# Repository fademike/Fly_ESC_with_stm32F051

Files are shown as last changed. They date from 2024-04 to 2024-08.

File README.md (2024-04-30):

# Fly_ESC_with_stm32F051
ESC for brushless motors.

git clone https://github.com/AlkaMotors/AM32-MultiRotor-ESC-firmware
git current project
cd AM32-MultiRotor-ESC-firmware
git apply am32ref_f051.patch (from current project)
May be to change make/tools: GCC_REQUIRED_VERSION ?= 10.3.1
make f051
STM32_Programmer_CLI -c port=swd -w ./obj/AM32_AM32REF_F051_2.00.bin 0x08000000 –verify -hardRst

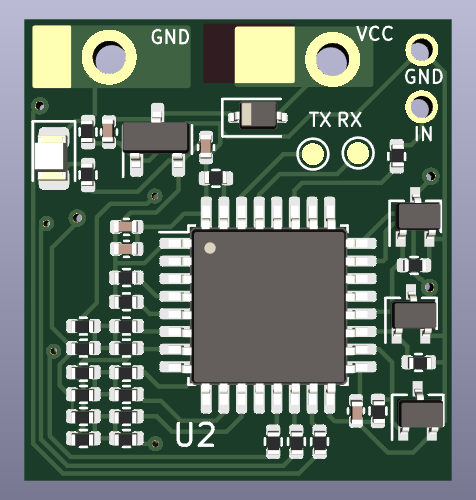
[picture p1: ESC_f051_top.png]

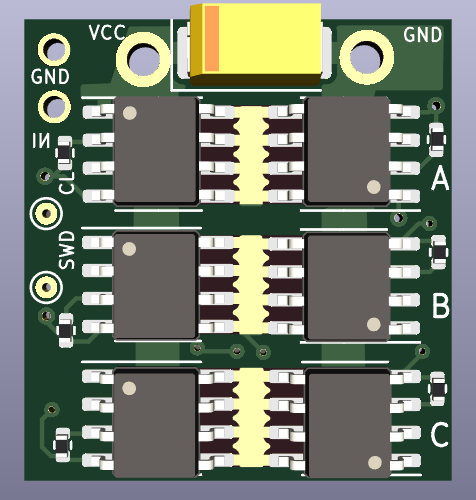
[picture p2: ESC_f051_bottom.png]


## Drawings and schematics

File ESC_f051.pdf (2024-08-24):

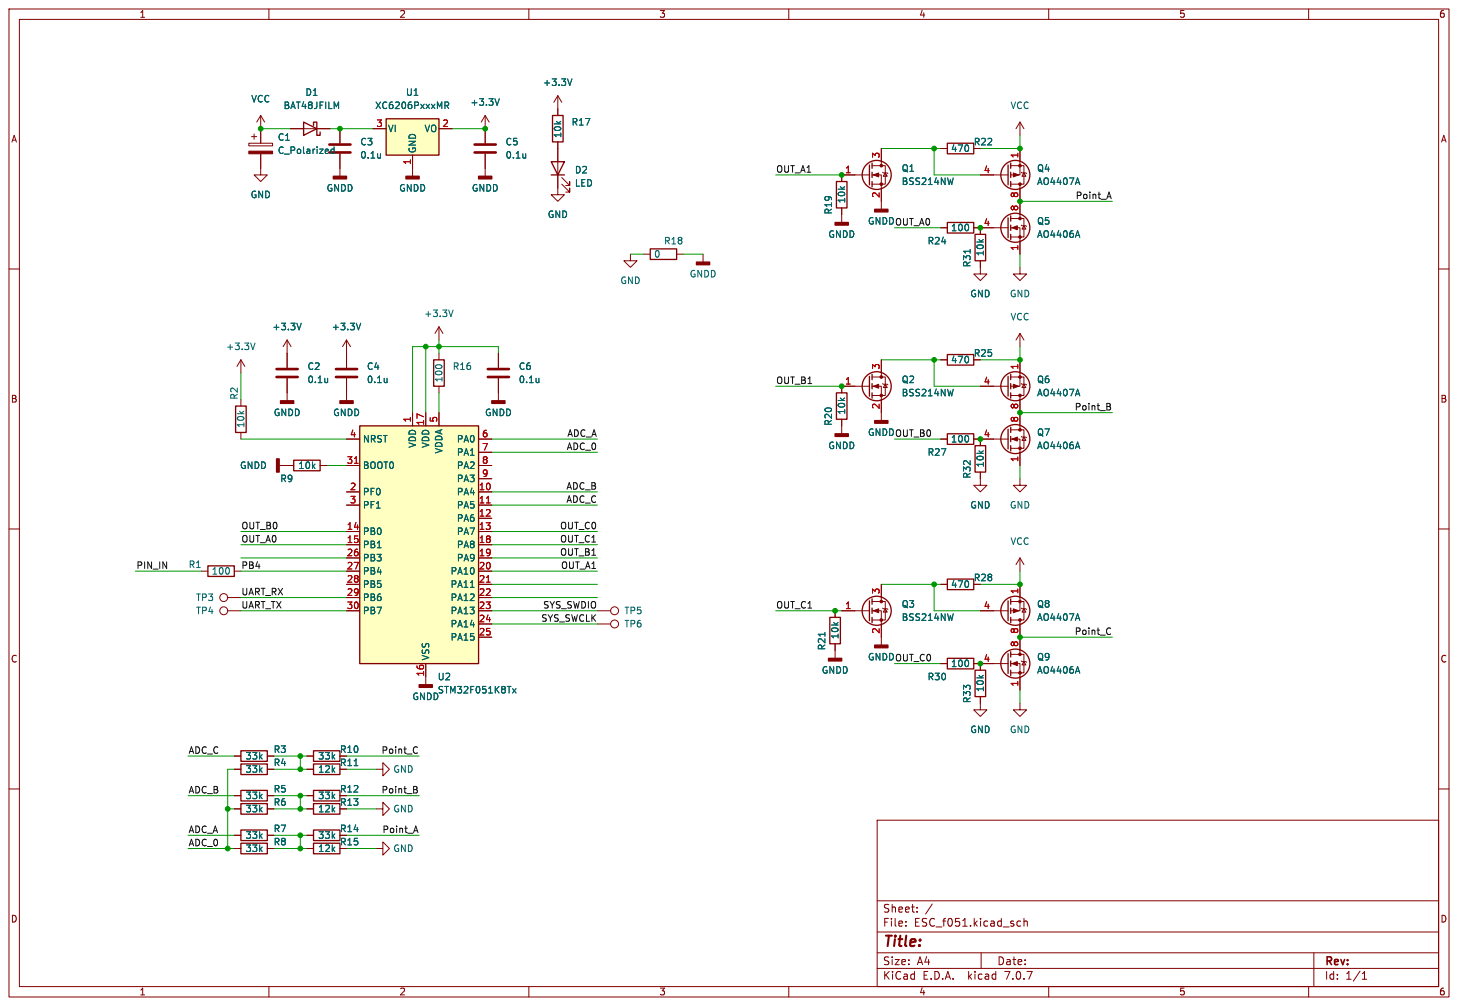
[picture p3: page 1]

Id: 1/1 Title: File: ESC_f051.kicad_sch Sheet: /

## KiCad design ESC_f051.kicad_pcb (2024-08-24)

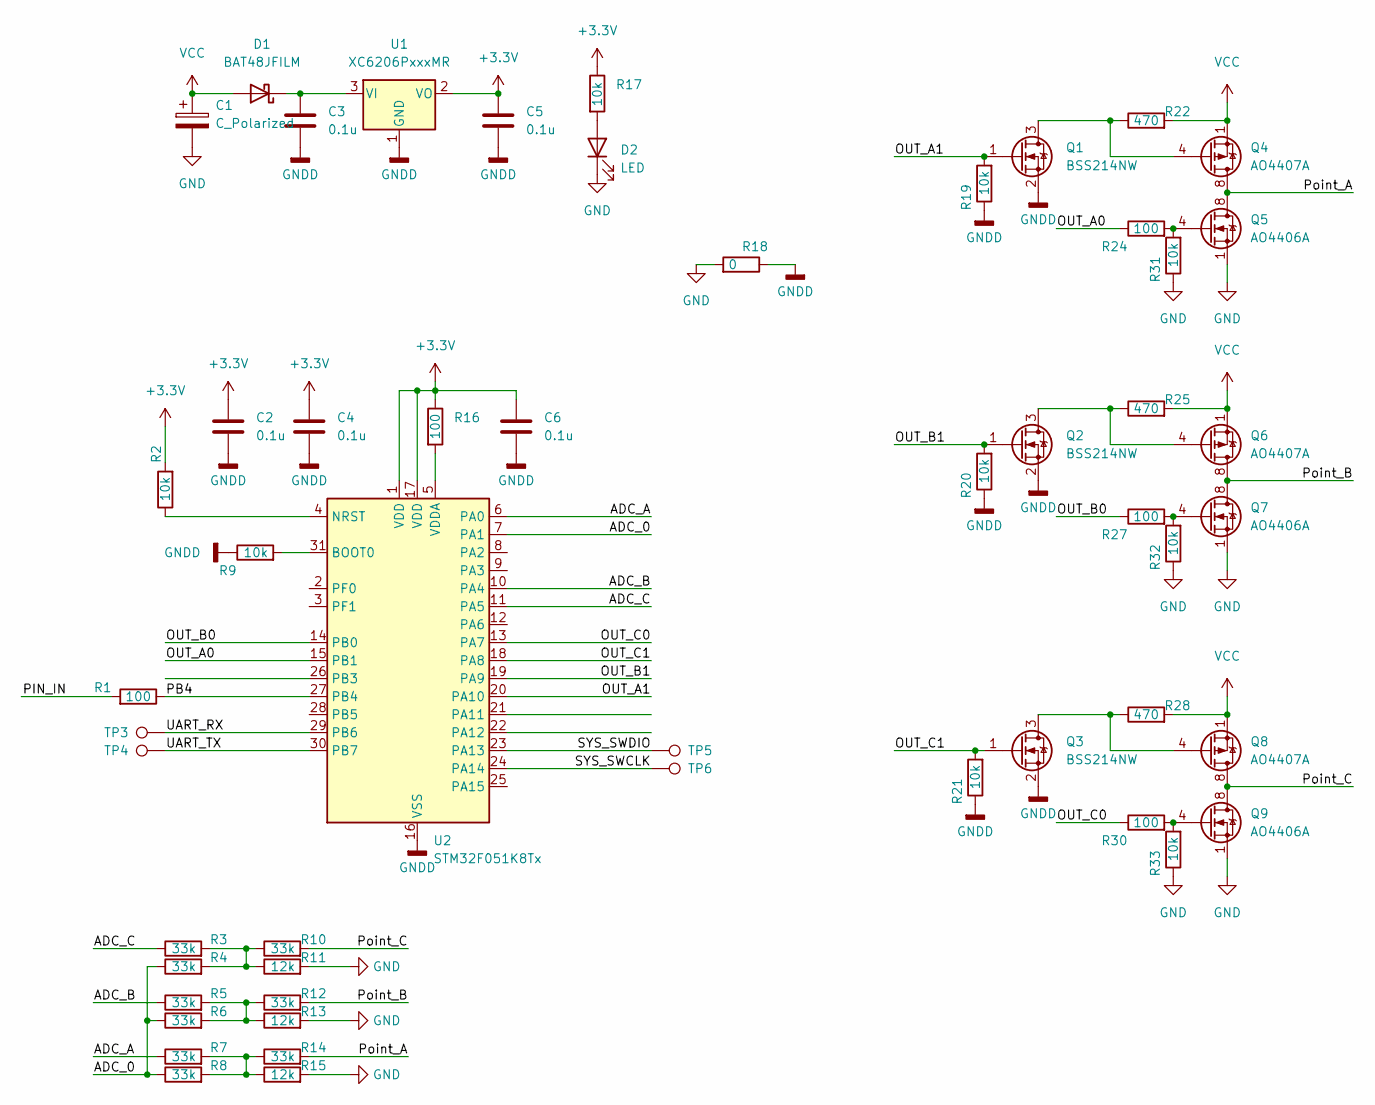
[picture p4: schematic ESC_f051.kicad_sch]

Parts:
C1: C_Polarized; CP_EIA-6032-28_Kemet-C
C2, C3, C4, C5, C6: 0.1u; C_0402_1005Metric
D1: BAT48JFILM; D_SOD-323
D2: LED; LED_0805_2012Metric
Q1, Q2, Q3: BSS214NW; SOT-323_SC-70
Q4, Q6, Q8: AO4407A; SOIC-8_3.9x4.9mm_P1.27mm
Q5, Q7, Q9: AO4406A; SOIC-8_3.9x4.9mm_P1.27mm
R1, R16, R24, R27, R30: 100; R_0402_1005Metric
R2, R9, R17, R19, R20, R21, R31, R32, R33: 10k; R_0402_1005Metric
R3, R4, R5, R6, R7, R8, R10, R12, R14: 33k; R_0402_1005Metric
R11, R13, R15: 12k; R_0402_1005Metric
R18: 0; R_0402_1005Metric
R22, R25, R28: 470; R_0402_1005Metric
TP3, TP4, TP5, TP6: TestPoint; TestPoint_Pad_D1.0mm
U1: XC6206PxxxMR; SOT-23
U2: STM32F051K8Tx; LQFP-32_7x7mm_P0.8mm

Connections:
+3.3V: C2.2, C4.2, C5.1, C6.2, R2.2, R16.1, R17.1, U1.2 (VO), U2.1 (VDD), U2.17 (VDD)
/ADC_0: R4.1, R6.1, R8.1, U2.7 (PA1)
/ADC_A: R7.1, U2.6 (PA0)
/ADC_B: R5.1, U2.10 (PA4)
/ADC_C: R3.1, U2.11 (PA5)
/OUT_A0: R24.1, U2.15 (PB1)
/OUT_A1: Q1.1 (G), R19.2, U2.20 (PA10)
/OUT_B0: R27.1, U2.14 (PB0)
/OUT_B1: Q2.1 (G), R20.2, U2.19 (PA9)
/OUT_C0: R30.1, U2.13 (PA7)
/OUT_C1: Q3.1 (G), R21.2, U2.18 (PA8)
/PB4: R1.1, U2.27 (PB4)
/PIN_IN: R1.2
/Point_A: Q4.5 (D), Q4.6 (D), Q4.7 (D), Q4.8 (D), Q5.5 (D), Q5.6 (D), Q5.7 (D), Q5.8 (D), R14.2
/Point_B: Q6.5 (D), Q6.6 (D), Q6.7 (D), Q6.8 (D), Q7.5 (D), Q7.6 (D), Q7.7 (D), Q7.8 (D), R12.2
/Point_C: Q8.5 (D), Q8.6 (D), Q8.7 (D), Q8.8 (D), Q9.5 (D), Q9.6 (D), Q9.7 (D), Q9.8 (D), R10.2
/SYS_SWCLK: TP6.1, U2.24 (PA14)
/SYS_SWDIO: TP5.1, U2.23 (PA13)
/UART_RX: TP3.1, U2.29 (PB6)
/UART_TX: TP4.1, U2.30 (PB7)
GND: C1.2, D2.1 (K), Q5.1 (S), Q5.2 (S), Q5.3 (S), Q7.1 (S), Q7.2 (S), Q7.3 (S), Q9.1 (S), Q9.2 (S), Q9.3 (S), R11.2, R13.2, R15.2, R18.2, R31.1, R32.1, R33.1
GNDD: C2.1, C3.2, C4.1, C5.2, C6.1, Q1.2 (S), Q2.2 (S), Q3.2 (S), R9.1, R18.1, R19.1, R20.1, R21.1, U1.1 (GND), U2.16 (VSS), U2.32 (VSS)
unnamed: C3.1, D1.1 (K), U1.3 (VI)
unnamed: D2.2 (A), R17.2
unnamed: Q1.3 (D), Q4.4 (G), R22.1
unnamed: Q2.3 (D), Q6.4 (G), R25.1
unnamed: Q3.3 (D), Q8.4 (G), R28.1
unnamed: Q5.4 (G), R24.2, R31.2
unnamed: Q7.4 (G), R27.2, R32.2
unnamed: Q9.4 (G), R30.2, R33.2
unnamed: R3.2, R4.2, R10.1, R11.1
unnamed: R5.2, R6.2, R12.1, R13.1
unnamed: R7.2, R8.2, R14.1, R15.1
unnamed: R9.2, U2.31 (BOOT0)
unnamed: R2.1, U2.4 (NRST)
unnamed: R16.2, U2.5 (VDDA)
VCC: C1.1, D1.2 (A), Q4.1 (S), Q4.2 (S), Q4.3 (S), Q6.1 (S), Q6.2 (S), Q6.3 (S), Q8.1 (S), Q8.2 (S), Q8.3 (S), R22.2, R25.2, R28.2

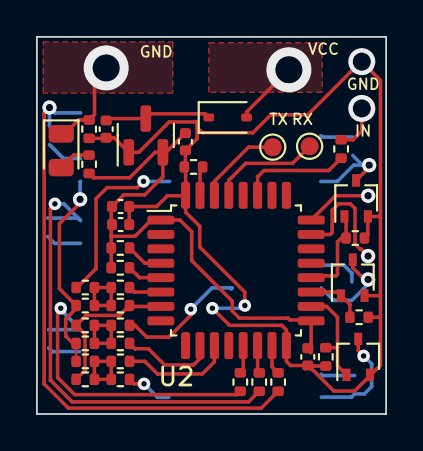
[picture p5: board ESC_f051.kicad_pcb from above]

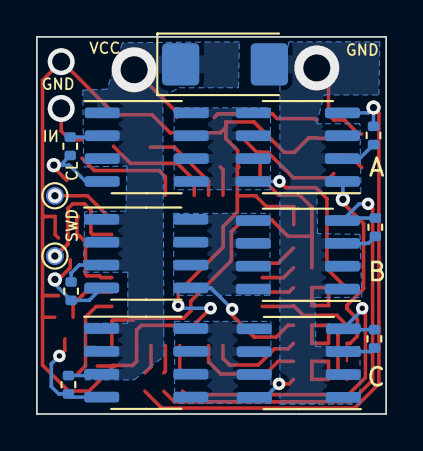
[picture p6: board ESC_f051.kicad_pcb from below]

Board: 2 copper layers, 19.4 x 20.9 mm, 53 parts (15 on the bottom side), 36 nets.

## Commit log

2024-04-30 remaked to kicad
    [ESC.PrjPCB, ESC.SchDoc, ESC_f051.kicad_pcb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]
2024-08-24 reduced the size
    [ESC_f051.kicad_pcb, ESC_f051.kicad_sch]
